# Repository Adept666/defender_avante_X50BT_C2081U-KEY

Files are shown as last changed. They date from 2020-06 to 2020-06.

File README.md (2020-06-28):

# defender_avante_X50BT_C2081U-KEY

Проект состоит из принципиальной схемы и чертежа печатного узла (ПУ) индикации и управления C2081U-KEY акустической системы Defender Avante X50BT. Чертежи созданы с помощью программы [KiCad](http://kicad-pcb.org) и предназначены для самостоятельного изготовления данного ПУ в случае выхода оригинального ПУ из строя и отсутствия возможности его ремонта.

SCH
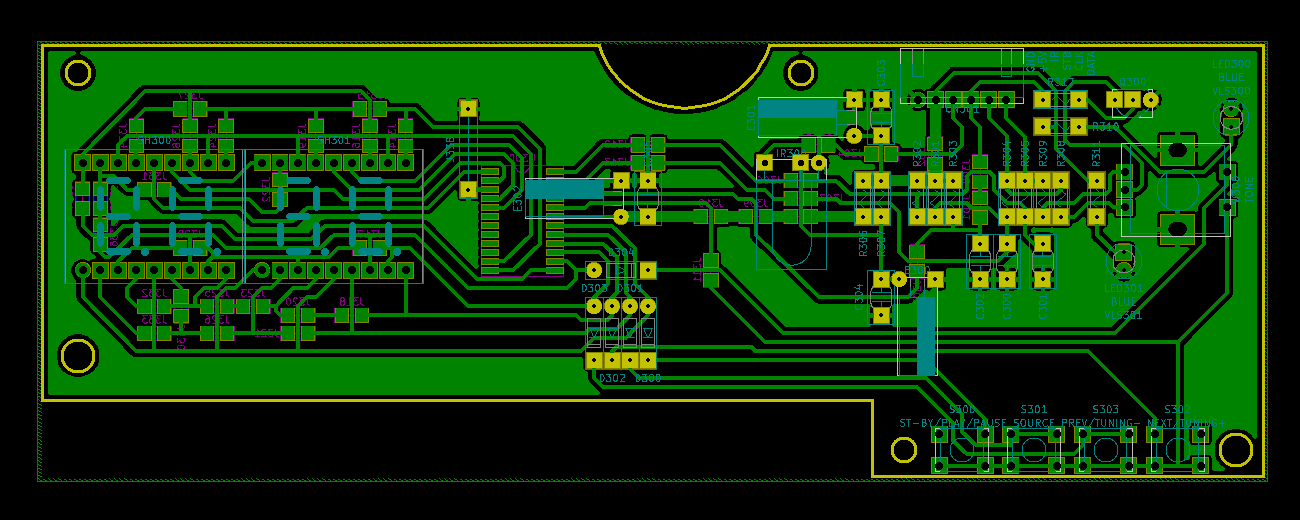
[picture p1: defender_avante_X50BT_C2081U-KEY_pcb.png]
PCB


## Requirements (Требования)

Работа с проектом осуществляется в программе [KiCad](http://kicad-pcb.org).

Для просмотра принципиальной схемы необходимо подключить следующие библиотеки символов:
* [KCL](http://github.com/Adept666/KCL) (файлы KCL.lib и ICL_TITAN_MICRO_ELECTRONICS.lib из репозитория [KCL](http://github.com/Adept666/KCL));
* библиотеку данного проекта (файл defender_avante_X50BT_C2081U-KEY.lib из данного репозитория).

Для просмотра чертежа ПУ подключение библиотек не требуется, так как все использованные футпринты вшиты в файл defender_avante_X50BT_C2081U-KEY.kicad_pcb. При необходимости футпринты могут быть найдены в библиотеке [KCL](http://github.com/Adept666/KCL).

## Author (Автор)

Igor Ivanov

## License (Лицензия)

This project is licensed under GNU General Public License v3.0 or later

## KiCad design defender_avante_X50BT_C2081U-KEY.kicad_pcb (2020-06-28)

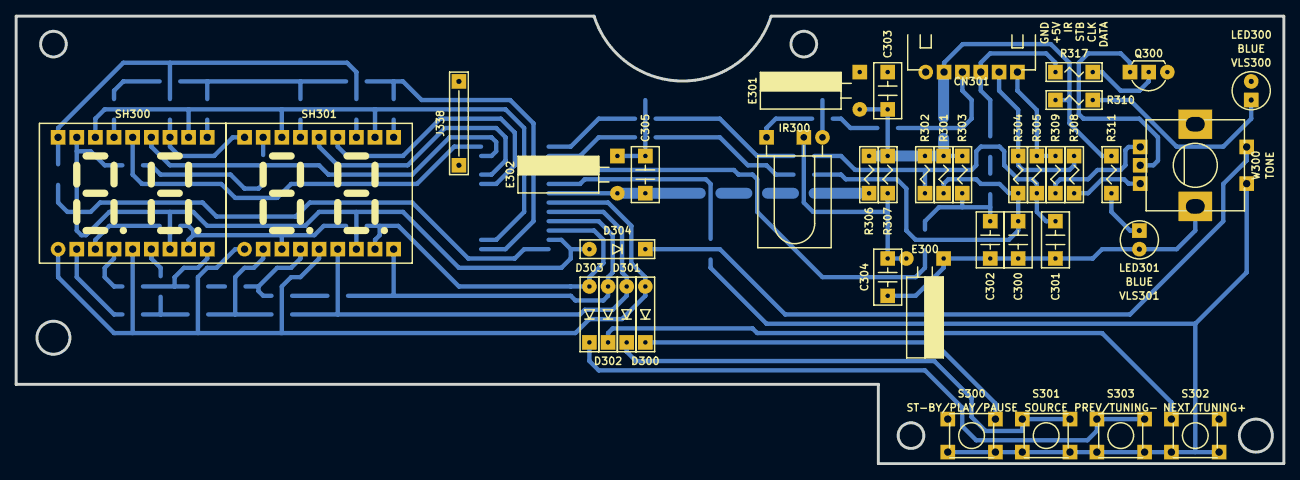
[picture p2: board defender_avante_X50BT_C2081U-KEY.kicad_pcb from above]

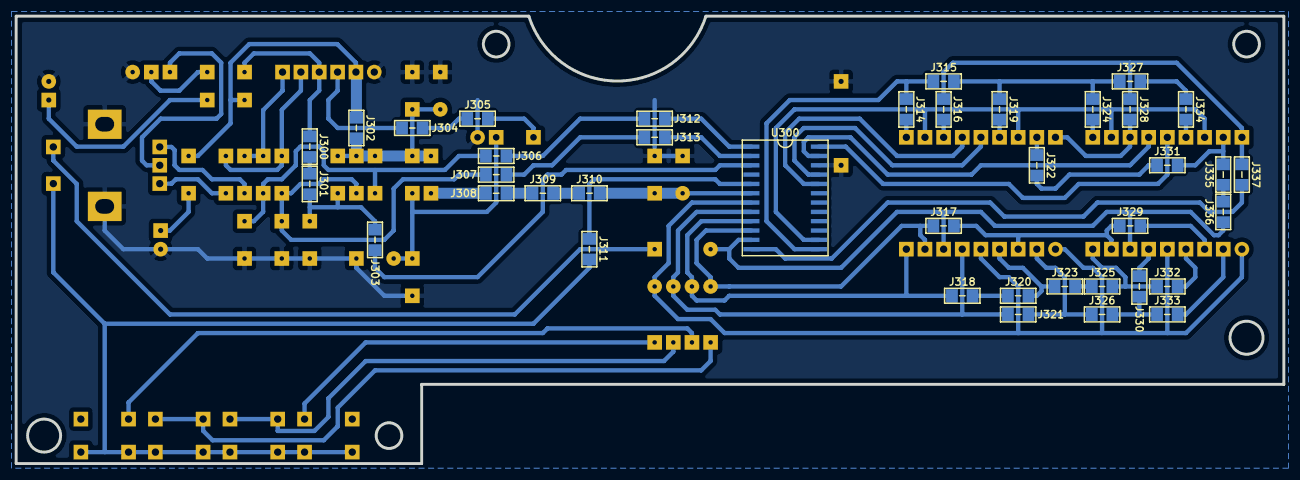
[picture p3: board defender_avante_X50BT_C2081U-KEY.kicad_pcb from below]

Board: 2 copper layers, 172.7 x 61.0 mm, 80 parts (39 on the bottom side), 34 nets.

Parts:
C300, C301, C302, C303, C304, C305: CAPACITOR_NON-POLARIZED; C-DISK-D04.2-T03.0-P05.08-d0.5
CN301: CONNECTOR_M_006_20_SPECIAL; CON-CWF-6RA
D300, D301, D302, D303, D304: DIODE_GENERAL; P-DO-35
E300: CAPACITOR_POLARIZED; CP-RADIAL-D05.0-P02.0-d0.5-L11-HD
E301, E302: CAPACITOR_POLARIZED; CP-RADIAL-D05.0-P02.0-d0.5-L11-HU
IR300: IC_IRR; IRR-CAST-GND-VCC-OUT-H
J300, J301, J302, J303, J304, J305, J306, J307, J308, J309, J310, J311, J312, J313, J314, J315, J316, J317, J318, J319, J320, J321, J322, J323, J324, J325, J326, J327, J328, J329, J330, J331, J332, J333, J334, J335, J336, J337: JUMPER; J-SM-1206
J338: JUMPER; J-TH-d0.6-P11.43
LED300, LED301: DIODE_LIGHT-EMITTING_LEFT; LED-ROUND-03.0-UNI-SH-SPACER
Q300: BJT_NPN_GENERAL; P-TO-92-E-B-C
R301, R302, R303, R304, R305, R306, R307, R308, R309, R310, R311, R317: RESISTOR_GENERAL; R-MFR-12
S300, S301, S302, S303: SWITCH_BUTTON_NON-LOCK_01P_01T_NO; SW-06XXX
SH300, SH301: DIODE_7SEG_2DIG_CC_S; LED-7SEG-DC56-11
U300: TM1668; P-SO-24W
VLS300, VLS301: VIRTUAL_LED-SPACER; VLS-BR
W300: ENCODER_CONTACTING_INC_B_C; ENC-PEC12R-4-F-S

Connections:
/A: SH300.1AA, SH300.2AA, SH301.1AA, SH301.2AA, U300.14
/B: J314.J, J315.J, J319.J, J324.J, J327.J, J334.J, SH300.1AB, SH300.2AB, SH301.1AB, SH301.2AB, U300.13
/C: D303.A, J317.J, J329.J, SH300.1AC, SH300.2AC, SH301.1AC, SH301.2AC, U300.10
/CLK: CN301.5, R304.1, R308.2
/D: D301.A, J321.J, J326.J, J330.J, J333.J, SH300.1AD, SH300.2AD, SH301.1AD, SH301.2AD, U300.8
/DATA: CN301.6, R305.1, R309.2
/DIG1: SH300.1C, U300.24
/DIG2: SH300.2C, U300.23
/DIG3: SH301.1C, U300.21
/DIG4: SH301.2C, U300.20
/DP: D302.A, J318.J, J320.J, J323.J, J325.J, J332.J, SH300.1AH, SH300.2AH, SH301.1AH, SH301.2AH, U300.9
/E: D300.A, SH300.1AE, SH300.2AE, SH301.1AE, SH301.2AE, U300.7
/F: J316.J, J328.J, J337.J, SH300.1AF, SH300.2AF, SH301.1AF, SH301.2AF, U300.12
/G: D304.A, J322.J, J331.J, J335.J, J336.J, SH300.1AG, SH300.2AG, SH301.1AG, SH301.2AG, U300.11
/IC_+5V: C305.1, E302.+, J308.J, J309.J, J310.J, R306.1, U300.6
/IC_CLK: C300.1, J307.J, J313.J, R301.1, R304.2, U300.2
/IC_DATA: C301.1, J306.J, J312.J, R302.1, R305.2, U300.1
/IR: CN301.3, IR300.OUT, J304.J, J305.J
/K2: J311.J, S300.NO, S301.NO, S302.NO, S303.NO, U300.5, W300.NO
/STB: C302.1, CN301.4, J300.J, J301.J, J303.J, R303.1, R317.1, U300.3
COM: C300.2, C301.2, C302.2, C303.2, C304.2, C305.2, CN301.1, E300.-, E301.-, E302.-, IR300.GND, J338.J, LED300.C, LED301.C, Q300.E, U300.22, W300.0
unnamed: C304.1, E300.+, IR300.VCC, R307.1
unnamed: D300.C, S300.COM
unnamed: D301.C, S301.COM
unnamed: D302.C, S302.COM
unnamed: D303.C, S303.COM
unnamed: D304.C, W300.COM
unnamed: LED300.A, R310.1
unnamed: LED301.A, R311.1
unnamed: Q300.B, R317.2
unnamed: Q300.C, W300.C
unnamed: R308.1, W300.B
unnamed: R309.1, W300.A
V: C303.1, CN301.2, E301.+, J302.J, R301.2, R302.2, R303.2, R306.2, R307.2, R310.2, R311.2

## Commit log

2018-12-17 Добавлен файл лицензии
2018-12-17 Впервые загружены файлы проекта
    [defender_avante_X50BT_C2081U-KEY.kicad_pcb, defender_avante_X50BT_C2081U-KEY.sch]
2019-02-17 Буквенная нумерация составных частей компонентов заменена на цифровую
2019-02-17 Свойства текстовых полей УГО приведены к единообразию. Показана мощность резисторов
    [defender_avante_X50BT_C2081U-KEY.kicad_pcb, defender_avante_X50BT_C2081U-KEY.sch]
2019-02-17 Удалены соединительные точки на шине
    [defender_avante_X50BT_C2081U-KEY.sch]
2019-02-17 Отредактирована библиотека проекта
2019-02-17 Применены собственные символы общей точки и питания
    [defender_avante_X50BT_C2081U-KEY.kicad_pcb, defender_avante_X50BT_C2081U-KEY.sch]
2019-02-17 Создано изображение схемы
2019-02-17 Создан файл README.md
2019-02-18 В связи с доработкой библиотеки обновлены футпринты диодов и светодиодов
    [defender_avante_X50BT_C2081U-KEY.kicad_pcb]
2019-02-18 Корректно выбраны значения свойсва Placement Type футпринтов
    [defender_avante_X50BT_C2081U-KEY.kicad_pcb]
2019-02-18 Обновлены футпринты (удалены примитивы на слое F.Paste)
    [defender_avante_X50BT_C2081U-KEY.kicad_pcb]
2019-02-18 Повторно выбраны значения свойсва Placement Type футпринтов
    [defender_avante_X50BT_C2081U-KEY.kicad_pcb]
2019-04-11 Скорректированы размеры платы, положение монтажных отверстий, кнопок, энкодера и светодиодов. Заменены держатели светодиодов
    [defender_avante_X50BT_C2081U-KEY.kicad_pcb, defender_avante_X50BT_C2081U-KEY.sch]
2019-04-23 В схему добавлены токоограничивающие резисторы R318...R325
    [defender_avante_X50BT_C2081U-KEY.sch]
2019-04-23 Положение элементов и печатных дорожек скорректировано с учётом новых размеров платы
    [defender_avante_X50BT_C2081U-KEY.kicad_pcb]
2019-04-24 Обновлено УГО ИМС
    [defender_avante_X50BT_C2081U-KEY.kicad_pcb, defender_avante_X50BT_C2081U-KEY.sch]
2019-05-15 Основные надписи схемы и платы дополнены комментариями о лицензии
    [defender_avante_X50BT_C2081U-KEY.kicad_pcb, defender_avante_X50BT_C2081U-KEY.sch]
2019-05-15 Исправлены связи новых резисторов. Удалены примитивы на слоях F.Cu и F.Mask
    [defender_avante_X50BT_C2081U-KEY.kicad_pcb]
2019-05-16 Токоограничивающие резисторы размещены на плате. Плата отредактирована
    [defender_avante_X50BT_C2081U-KEY.kicad_pcb]
2019-05-23 Обновлено УГО ИМС. ИМС и обвязка временно размещены за пределами листа
    [defender_avante_X50BT_C2081U-KEY.sch]
2019-05-23 Удалён поролоновый держатель
    [defender_avante_X50BT_C2081U-KEY.kicad_pcb, defender_avante_X50BT_C2081U-KEY.sch]
2019-05-23 Занулены координаты футпринта E300
    [defender_avante_X50BT_C2081U-KEY.sch]
2019-05-23 В схему включены виртуальные держатели для светодиодов
    [defender_avante_X50BT_C2081U-KEY.sch]
2019-05-23 Применён символ энкодера с выводом корпуса
    [defender_avante_X50BT_C2081U-KEY.sch]
2019-06-03 Удалена лишняя перемычка J314
    [defender_avante_X50BT_C2081U-KEY.kicad_pcb, defender_avante_X50BT_C2081U-KEY.sch]
2019-06-04 Схема и плата оформлены корректно
    [defender_avante_X50BT_C2081U-KEY.kicad_pcb, defender_avante_X50BT_C2081U-KEY.sch]
2019-09-02 Обновлена библиотека проекта
2019-09-02 Повёрнуты светодиоды. Залочены футпринты энкодера и разъёма
    [defender_avante_X50BT_C2081U-KEY.kicad_pcb]
2019-09-04 Проект скорректирован с учётом изменений в УГО и ФП переключателей
    [defender_avante_X50BT_C2081U-KEY.kicad_pcb, defender_avante_X50BT_C2081U-KEY.sch]
2019-09-04 Плата скорректирована с учётом изменений в ФП семисегментных индикаторов
    [defender_avante_X50BT_C2081U-KEY.kicad_pcb]
2019-09-06 Перемещено одно из монтажных отверстий
    [defender_avante_X50BT_C2081U-KEY.kicad_pcb]
2019-09-06 Удалена поясняющая надпись
    [defender_avante_X50BT_C2081U-KEY.sch]
2019-09-06 Осуществлён переход к ревизии 3
    [defender_avante_X50BT_C2081U-KEY.kicad_pcb, defender_avante_X50BT_C2081U-KEY.sch]
2019-09-16 Обновлены футпринты R-MFR-12
    [defender_avante_X50BT_C2081U-KEY.kicad_pcb]
2019-09-24 Ширина шины питания увеличена с 0.6 до 1.5 мм
    [defender_avante_X50BT_C2081U-KEY.kicad_pcb, defender_avante_X50BT_C2081U-KEY.sch]
2019-11-11 Удалены резисторы R318…R325
    [defender_avante_X50BT_C2081U-KEY.kicad_pcb, defender_avante_X50BT_C2081U-KEY.sch]
2020-03-05 Добавлена выводная перемычка J338
    [defender_avante_X50BT_C2081U-KEY.kicad_pcb, defender_avante_X50BT_C2081U-KEY.sch]
2020-03-05 Создан файл sym-lib-table
2020-03-05 Положение дорожек скорректировано в связи с удалением резисторов. Удалены верхние слои КП J338
    [defender_avante_X50BT_C2081U-KEY.kicad_pcb]
2020-03-05 Создан земляной полигон
    [defender_avante_X50BT_C2081U-KEY.kicad_pcb]
2020-03-05 Удалено отчество в README.md
2020-03-05 Удалено отчество на чертежах
2020-03-05 Удалены резервные копии
2020-06-28 Схема и плата обновлены в связи с переименованием ФП перемычек
    [defender_avante_X50BT_C2081U-KEY.kicad_pcb, defender_avante_X50BT_C2081U-KEY.sch]
2020-06-28 Создано изображение печатного узла
2020-06-28 Расширено описание проекта
